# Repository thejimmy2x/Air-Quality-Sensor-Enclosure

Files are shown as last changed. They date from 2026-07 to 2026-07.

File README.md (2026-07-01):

# Sensor Stack Enclosure

Parametric, lidded desk enclosure for a multi-sensor air-quality stack, designed in
Fusion 360 (driven by User Parameters) for FDM printing (PETG/ASA, 0.6 mm nozzle).

## Sensor stack
| Board | Size (mm) | Role |
|---|---|---|
| ESP32-S3-DevKitC-1 | ~70 × 28 × 13 | MCU, heat source, external USB-C |
| PMS5003 | 50 × 38 × 21 | Particulate, fan, needs fresh ambient air |
| SCD40 (Adafruit) | ~26 × 18 × 8 | CO2, heat-sensitive |
| BME680 (Adafruit) | ~25 × 18 × 6 | VOC/T/RH/P, heat-sensitive |
| SGP40 (Adafruit) | ~25 × 18 × 5 | VOC index |

## Design
- **External:** ~155 × 83 × 39 mm. Low, wide slab; hex-honeycomb vents; filleted
  corners; chamfered floating base.
- **Thermal zoning:** hot back (PMS + ESP32) vs. cool front (gas sensors); SCD40
  placed farthest from heat.
- **Airflow:** passive honeycomb venting (front + both sides) for the gas sensors;
  PMS5003 isolated with a dedicated round fan-intake port + exhaust on the back wall.
- **Closure:** screw-down lid, M3 heat-set brass inserts (4 corners).
- **Features:** external USB-C port, status-LED light-pipe, removable carrier tray.

## Components (print each once)
- `export/base.3mf` / `.stl` — outer shell with vents, ports, insert bosses
- `export/tray.3mf` / `.stl` — removable sensor carrier (pockets, PMS/ESP cradles)
- `export/lid.3mf` / `.stl` — screw-down lid
- `export/sensor_enclosure_assembly.step` — full assembly (CAD interchange)

## Status
v1 complete. Fit-check TBDs (all parameterized): PMS intake/exhaust exact port
positions, LED light-pipe height, USB-C cutout size/height. See `STATE.md`.

## Build notes
- Fusion source is parametric (49 User Parameters). The Base is generated by a single
  consolidated script; clearances tuned for a 0.6 mm nozzle (pocket +0.5, tray 0.25,
  lid lip 0.4, M3 insert pilot 4.1 mm).

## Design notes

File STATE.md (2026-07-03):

# STATE — Sensor Stack Enclosure

**Project:** Sensor Enclosure (JDP3D) | **Owner:** Jimmy Pezzone
**Active track:** enclosure-v1
**Last updated:** 2026-07-01

## Current state
Working doc = **"Sensor_Case"** in Fusion (NOT saved — Jimmy saves manually).
Doc is now MULTI-COMPONENT: root has 3 occurrences — **Base** (body BaseShell),
**Tray** (TrayBody), **Lid** (LidBody), each its own component. (A separate
"Sensor_Case_snap" doc exists — DISREGARD it, not canonical.) v1 + fit-check
revisions applied:
- Tray + PMS5003 FIT CONFIRMED good (physical).
- Corner-post clearance scallops added; PMS intake raised; ESP/SGP share a wall.
- Gas-sensor bays reworked: side-wall wire channels + enlarged SCD-40 (see below).
- **PMS 4-hole air inlet ported (2026-07-01, see below).**
- **ESP USB port widened to dual-USB-C slot (2026-07-02, see below).**
Next: physical fit-test of the 3 gas sensors in the reworked bays; then RE-EXPORT
base (raised intake + new inlet slot are in NO exported file yet). GitHub main is
current through the gas-bay rework (commit c07a783), tray export = Sensor_Case_Tray_Final.stl.
Full plan: `C:\Users\jdp63\.claude\plans\i-have-a-sensor-quizzical-owl.md`

## Model summary (Fusion, 55 user params driving geometry)
- External size: **155.2 × 83.2 × ~39.4 mm** (base 32.4 tall + lid 7).
- Interior: 150 × 78 × 30 mm.
- **Base** (comp Base / body BaseShell): filleted shell, chamfered floating base,
  4 corner insert bosses (Ø8, 4.1mm pilot for M3 heat-set), back-wall ports
  (PMS fan Ø22 @ X25 + PMS 4-hole inlet slot @ X50/Z23.4 + ESP dual-USB-C slot
  @ X113-137/Z5.4-12.4), honeycomb
  vents front + both sides, LED light-pipe port. NOTE: PMS vent face has ONLY a fan
  + a 4-hole inlet row (no separate exhaust — old "rect exhaust" was a misconception).
- **Tray** (1 body): floor 2.5mm; 4 corner-post scallops (r=5.5, clears Ø8 posts);
  3 gas-sensor bays with wire channels on BOTH side (±X) walls — SCD40 26.5×23.8,
  BME680/SGP40 26.4×18.8; PMS cradle (open back → intake), ESP cradle (open back →
  USB), 2 front finger scallops. Full length 149.5 (0.25mm/side to cavity).
  NOTE base intake circle raised +2mm so tray floor no longer blocks it.
- **Lid** (1 body): 3mm plate, matching fillet + top chamfer, register lip (0.4mm
  clr, corner-notched), 4 M3 screw counterbores aligned to inserts.

## Board layout (mm, interior min-corner x0,y0)
scd(12,12) bme(50,12) sgp(85,12) | pms(12,38) esp(112,6). Corner bosses (4,4)(146,4)(4,74)(146,74).
Thermal zoning: hot back (PMS+ESP) vs cool front (gas sensors); SCD40 front-left, farthest from ESP.

## Exports (X:\JDP3D\sensor enclosure\export\)
sensor_enclosure_assembly.step + base/tray/lid .3mf + .stl (High refinement).

## Gas-sensor bay rework (2026-07-01, after tray/PMS fit confirmed good)
Tray + PMS5003 now fit perfectly. Reworked the 3 gas-sensor bays:
- WIRE CHANNELS were on the wrong wall (back +Y). Real Adafruit boards have
  STEMMA-QT connectors on LEFT+RIGHT (+/-X) edges. Solid side walls were also
  blocking the connectors from seating -> that was the "bays too small" symptom.
  Fix: channels moved to BOTH side walls (8mm wide, Y17-25), all 3 bays
  ("both ends wired out"). Old back notches removed.
- SCD-40 genuinely too small: board 25.5 x 22.8mm, bay was 19 deep. Enlarged
  bay to 26.5(X) x 23.8(Y), grown front+back; back wall clears PMS cradle 1.40mm.
- BME680/SGP40 bays set to 26.4 x 18.8 (fits 25.4 x 17.8 std footprint).
- SGP40 right channel breaches the shared SGP/ESP wall (routes to ESP).
- Implementation: DELETED old pocket joins+notch cuts (Extrude3-8, Sketch3-8),
  REBUILT 3 pockets (Pocket_SCD40/BME680/SGP40) + 6 channels (Chan_*_L/R) on
  the Z=4.9 floor-top plane (Plane2). Rebuild needed because sketches are
  unconstrained rects (can't edge-drag cleanly). Single valid body, all healthy.
- Board dims: SCD40 25.5x22.8 (Adafruit 5187, confirmed); BME680/SGP40 taken as
  25.4x17.8 std STEMMA-QT (Adafruit hides exact dims in image-only fab prints).
  VERIFY BME680/SGP40 footprints at physical fit; enlarge if needed.

## PMS5003 four-hole air inlet — ported (2026-07-01)
Problem: base back wall had NO opening for the PMS's 4 clean-air INLET holes (only
the fan Ø22 + a mislocated "exhaust" rect). Per datasheet the vent face has only a
fan + a 4-hole inlet row — no exhaust. The old rect (Base Sketch6/Extrude6, symmetric
cut on wall midplane Y=79.3) was at the right X/width but wrong height (Z9.9-18.9),
so the holes (world Z~23.4, up near the sensor top) sat against solid wall.
Fix: deleted old Extrude6 (heals wall), redrew Sketch6 rect, rebuilt symmetric cut
-> INLET SLOT world X42-58 (16mm) × Z20.9-25.9 (5mm), centered X50/Z23.4. Covers
all 4 holes (world X44-56) + ~2mm seat play. Fan Ø22 @ X25 left untouched.
Verified via pointContainment: slot = through-opening (matches fan/USB signature),
old-exhaust spot now solid. BaseShell single healthy body.
Sketch6 coord map (for future edits): sketch x = world X (cm); sketch y = -(world Z);
plane Y=7.93cm (wall midplane); symmetric cut 3.45mm/side clears 2.6mm wall.
TODO Jimmy: SAVE doc + RE-EXPORT base .3mf/.stl (slot not in any export yet).

## ESP32-S3 dual-USB-C port — widened (2026-07-02)
Board = ESP32-S3-DevKitC-1-N32R16V: has TWO USB-C connectors on its end (native
USB + UART), but base had only ONE centered cutout (X120-132) -> one cable couldn't
seat. Espressif docs give board outline but NOT connector X-positions (image-only).
Estimated connector centers ~world X119 & X130.5 (pair centered on 25.5mm board end,
board spans X112-137.5). Chose robust fix: ONE wide "letterbox" slot spanning the
full board end -> Base Sketch7/Extrude7 rebuilt to world X113-137 (24mm) × Z5.4-12.4,
symmetric cut through back wall. Guaranteed to clear both connectors regardless of
exact placement; wall solid outside X113-137. Verified via pointContainment.
If you ever want two neat cutouts instead: measure the two port centers + widths.
TODO Jimmy: SAVE + RE-EXPORT base (slot not in any export yet).

## Hardware spec — closure (read off Sensor_Case geometry 2026-07-01)
- Inserts: **M3 brass heat-set**, set into the 4 BASE corner POSTS (Ø8 boss),
  one per corner. Pocket = Ø4.1 x 6mm deep BLIND hole in each post TOP face
  (Z 26.4..32.4); install from top (lid side). NOT in the lid.
- Insert part: standard M3 (~4.0mm OD, ~5.7mm long, e.g. CNC Kitchen M3x5.7 or
  generic M3x5/M3x4). Do NOT use extra-long M3 (would bottom out in 6mm pocket).
- Screws: **M3 socket-head cap, ~M3x8** (M3x10 ok for max engagement). Head
  recesses in lid Ø6.2 x 3mm counterbore; lid clears post top via Ø9.8 recess;
  ~5mm thread engages the insert. No separate Ø3.4 lid clearance hole (Ø9.8 recess
  serves that). 4 screws total, one per corner.

## Locked decisions
- Fusion MCP parametric; screw-down lid + M3 heat-set inserts (no gasket).
- Passive honeycomb venting; PMS isolated w/ round fan-intake port + exhaust.
- Hex honeycomb aesthetic; USB-C port, LED light-pipe, removable carrier tray.
- Material/print: PETG or ASA, 0.6mm nozzle, walls 2.6 / floor 2.4.
- Clearances (0.6mm nozzle): pocket +0.5, tray 0.25, lid lip 0.4, insert pilot 4.1.

## Fit-check revisions (2026-07-01, doc "Sensor_Case" — NOT the NoInserts doc)
Physical fit-check drove 3 direct-geometry edits (sketches are script-built, no
parametric dims, so param changes don't move geometry — edited geometry directly):
1. Tray ESP/SGP compartment overlap: shifted SGP pocket (Sketch7 + wire-notch
   Sketch8) -0.6mm X. SGP right wall now X[109.90..111.50] == ESP cradle left wall
   -> single SHARED 1.6mm wall (was 2.2mm interpenetration).
2. Tray hit the 4 corner POSTS (base screw bosses Ø8 / r=4 at (4,4)(4,74)
   (146,4)(146,74), full-height). The 1.85mm left-edge trim did NOT fix this
   (posts are at the corners, not along the edge) -> REVERTED that trim.
   Real fix: feature "CornerPostClearance" = 4 circular corner cutouts r=5.5
   (Ø11) centered on each boss. Clears Ø8 posts by 1.55mm radial; tray restored
   to full length 149.5mm (snug in 150 cavity -> stays located over the intake).
   Note: r=5.5 chosen because corner tip is 5.30mm from boss center; a smaller
   r (tried 4.6) isolates the tip as a <1mm3 sliver, and deleting slivers via
   body.deleteMe() also deletes the parent cut feature -> use r>=tip distance.
3. PMS intake was blocked ~1.5mm by tray floor: raised base intake circle
   (Sketch5) +2.0mm. Center world Z 14.4 -> 16.4; bottom 3.4 -> 5.4, clears tray
   floor top (4.89) by +0.51mm. Exhaust unaffected (bottom already ~9.9).
NOTE: Tray is a REMOVABLE carrier (separate print), NOT print-in-place.
TODO for Jimmy: SAVE the doc manually + RE-EXPORT tray.3mf/.stl and base.3mf/.stl
(current repo exports are pre-revision). Intake clearance is thin (0.51mm) — raise
more if you want margin, but that walks away from the real PMS fan center (still TBD).

## Open items / fit-check TBDs
- [x] PMS5003 port coords RESOLVED via datasheet (Downloads\pms5003.jpg). Vent
      face (50×21, against back wall) = fan Ø12 @ 35.80mm from left edge + 4 inlet
      holes (row, 6mm from left, 12mm span/4mm pitch, 2.45mm below top edge).
      Sensor seated hole/fan-end toward +X (ESP side): fan→world X~26 (under Ø22),
      holes→world X44-56 near top (world Z~23.4). See PMS inlet section below.
- [ ] LED light-pipe height (front wall X126, Z25mm) — align to actual ESP LED.
- [ ] USB-C cutout height/size vs actual connector.
- [ ] Board heights/pocket depths at physical test fit.
- Honeycomb finalized: hex_af=5mm, rib=1.0mm, compact centered windows
  (front X35-115, left Y10-45, right Y33-68, Z band fl+5..fl+22). Base is now
  built by ONE consolidated script (shell+bosses+ports+LED+vents) -> easy to retune.

## Reusable notes / gotchas
- Fusion rejects param names 'wall' and 'floor' (reserved) -> used wall_t, floor_t.
- userParameter.value is in cm (internal units); positions built via mm()/10.
- Corner-notch circles can leave tiny disconnected slivers -> delete bodies <50mm3.
- Never save the Fusion document. Fusion MCP not thread-safe -> sequential calls only.
- MCP gotcha: Fusion MCP tools only load into a Claude Code session at startup;
  had to /reload-plugins (or restart session) after connecting the server.

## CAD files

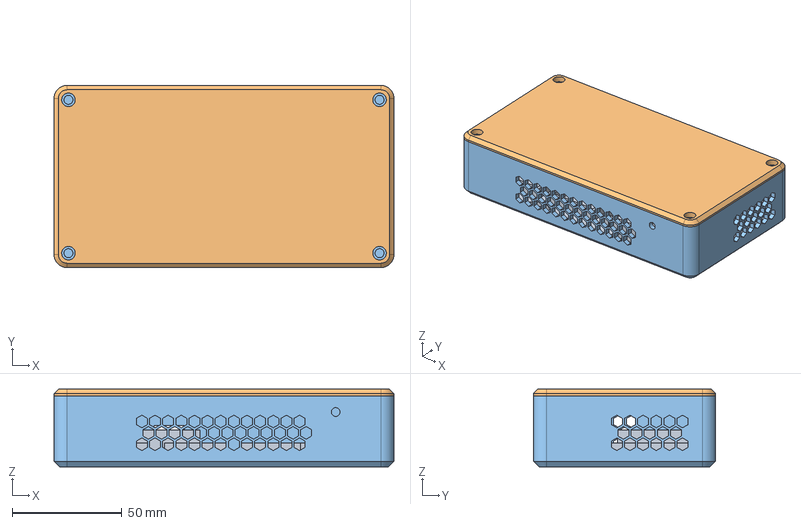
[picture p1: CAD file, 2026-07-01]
export/sensor_enclosure_assembly.step
155.2 x 83.2 x 35.4 mm
Base

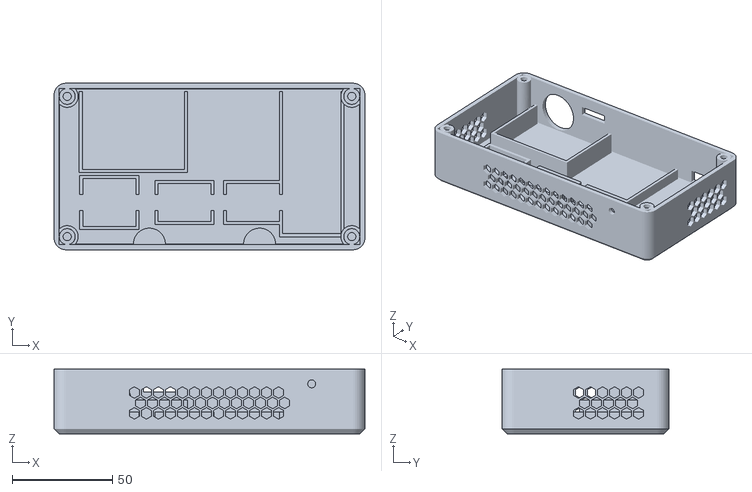
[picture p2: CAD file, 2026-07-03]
export/Sensor_Case.stl
155.2 x 83.2 x 32.4

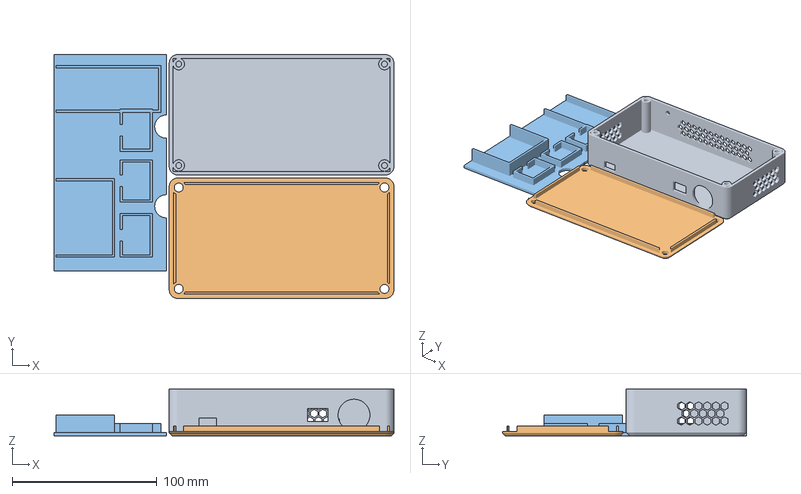
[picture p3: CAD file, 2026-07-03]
export/TestPrint1.3mf
234.7 x 168.4 x 32.4 mm
base.stl
lid.stl
tray.stl

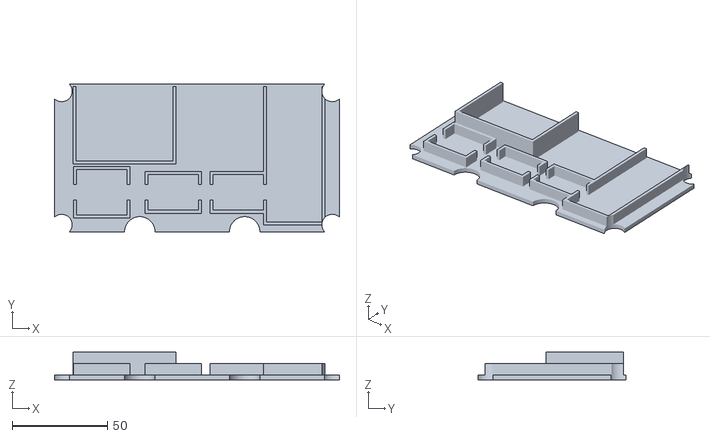
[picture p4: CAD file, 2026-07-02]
export/Sensor_Case_Tray_Final.stl
149.5 x 77.5 x 14.5

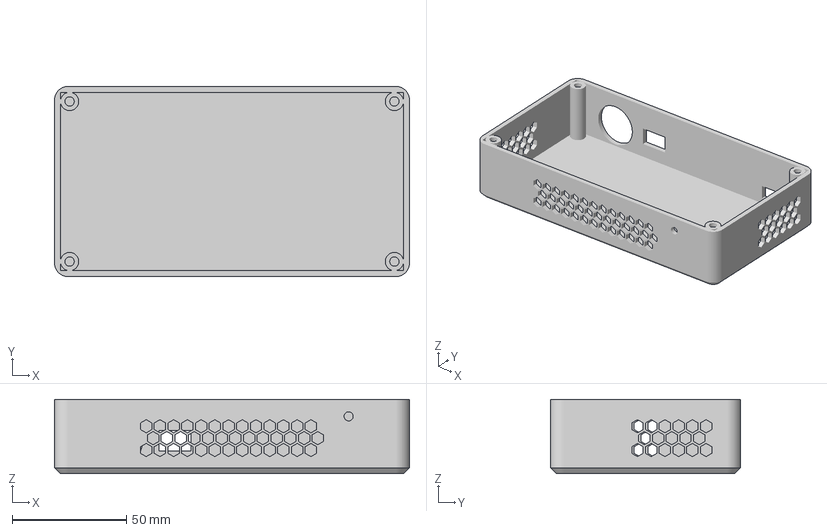
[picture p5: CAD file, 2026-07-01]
export/base.3mf
155.2 x 83.2 x 32.4 mm

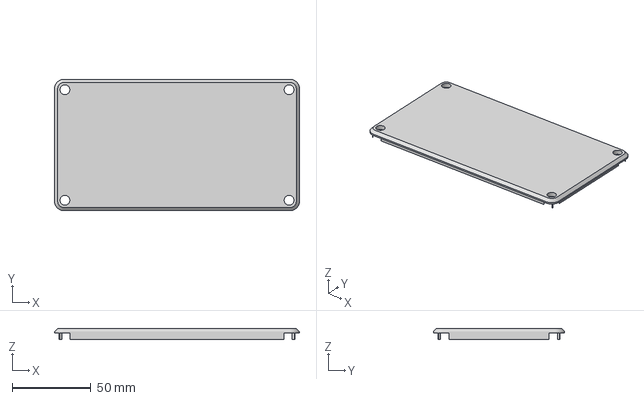
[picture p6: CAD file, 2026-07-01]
export/lid.3mf
155.2 x 83.2 x 7.00 mm

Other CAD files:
export/base.stl
export/lid.stl

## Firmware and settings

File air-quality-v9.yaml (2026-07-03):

esphome:
  name: air-quality-monitor
  friendly_name: Air Quality Monitor

esp32:
  board: esp32-s3-devkitc-1
  framework:
    type: esp-idf

wifi:
  ssid: !secret wifi_ssid
  password: !secret wifi_password
  ap:
    ssid: "Air-Quality-Monitor"
    password: !secret ap_password

captive_portal:

api:
  reboot_timeout: 0s

ota:
  - platform: esphome

web_server:
  port: 80

prometheus:

i2c:
  sda: GPIO8
  scl: GPIO9
  frequency: 100kHz

logger:
  hardware_uart: USB_SERIAL_JTAG
  level: DEBUG
  logs:
    pmsx003: WARN
    bme680.sensor: WARN
    scd4x: WARN
    sgp4x: WARN
    sensor: WARN

uart:
  id: uart_pms
  rx_pin: GPIO16
  tx_pin: GPIO17
  baud_rate: 9600

# Globals for tracking previous CO2 value and VOC baseline
globals:
  - id: previous_co2
    type: float
    restore_value: no
    initial_value: '0.0'
  - id: previous_co2_time
    type: unsigned long
    restore_value: no
    initial_value: '0'
  - id: voc_baseline
    type: float
    restore_value: yes
    initial_value: '100.0'

sensor:
  - platform: bme680
    temperature:
      name: "Temperature"
      id: bme_temperature
    pressure:
      name: "Pressure"
    humidity:
      name: "Humidity"
      id: bme_humidity
    gas_resistance:
      name: "Gas Resistance"
    address: 0x77
    update_interval: 30s
    heater:
      temperature: 320
      duration: 150ms

  - platform: pmsx003
    type: PMSX003
    uart_id: uart_pms
    pm_1_0:
      name: "PM1.0 Concentration"
      id: pm_1_0      
    pm_2_5:
      name: "PM2.5 Concentration"
      id: pm_2_5
    pm_10_0:
      name: "PM10.0 Concentration"
      id: pm_10_0

  - platform: scd4x
    co2:
      name: "CO2"
      id: co2_sensor
      on_value:
        then:
          - lambda: |-
              unsigned long now = millis();
              if (id(previous_co2_time) > 0) {
                float dt_min = (now - id(previous_co2_time)) / 60000.0;
                if (dt_min > 0) {
                  float rate = (x - id(previous_co2)) / dt_min;
                  id(co2_rate).publish_state(rate);
                }
              }
              id(previous_co2) = x;
              id(previous_co2_time) = now;
    temperature:
      name: "SCD41 Temperature"
    humidity:
      name: "SCD41 Humidity"
    update_interval: 60s

  - platform: sgp4x
    voc:
      name: "VOC Index"
      id: voc_index
      on_value:
        then:
          - lambda: |-
              // Update rolling baseline slowly (1% new reading, 99% old baseline)
              // This gives a ~100 sample trailing average
              id(voc_baseline) = (id(voc_baseline) * 0.99) + (x * 0.01);
              id(voc_deviation).publish_state(x - id(voc_baseline));
    compensation:
      humidity_source: bme_humidity
      temperature_source: bme_temperature

  # CO2 Rate of Change (ppm per minute)
  - platform: template
    name: "CO2 Rate of Change"
    id: co2_rate
    unit_of_measurement: "ppm/min"
    accuracy_decimals: 1
    icon: "mdi:trending-up"

  # VOC Deviation from baseline (positive = spike above normal)
  - platform: template
    name: "VOC Deviation"
    id: voc_deviation
    unit_of_measurement: ""
    accuracy_decimals: 1
    icon: "mdi:air-filter"

  # PM2.5 / PM10 Ratio (higher = more fine particles, combustion/off-gassing)
  - platform: template
    name: "PM2.5/PM10 Ratio"
    unit_of_measurement: ""
    accuracy_decimals: 2
    update_interval: 60s
    icon: "mdi:chart-donut"
    lambda: |-
      if (id(pm_10_0).state > 0) {
        return id(pm_2_5).state / id(pm_10_0).state;
      } else {
        return 0;
      }

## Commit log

2026-07-01 Initial commit: sensor stack enclosure v1
    Parametric Fusion 360 desk enclosure for ESP32-S3 + PMS5003 + SCD40 +
    BME680 + SGP40. Hex-honeycomb vents, thermal zoning, screw-down lid with
    M3 heat-set inserts, removable carrier tray. Includes STEP assembly and
    per-part 3MF/STL exports.
    [base.3mf, base.stl, lid.3mf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]
2026-07-01 Tray fit-check revisions: shared ESP/SGP wall, corner post clearances, raised PMS intake
    - ESP32/SGP compartments: shift SGP pocket -0.6mm so it shares one 1.6mm
    wall with the ESP cradle (was a 2.2mm interpenetration)
    - Corner fit: 4 circular corner cutouts (r=5.5) to clear the base Ø8
    screw posts; tray kept full length so it stays located over the intake
    - PMS5003 intake raised +2.0mm so it clears the tray floor (was ~1.5mm blocked)
    - Add revised tray export (Sensor_Case-TrayRev1.stl); log details in STATE.md
    [Sensor_Case-TrayRev1.stl]
2026-07-02 Rework gas-sensor bays: side-wall wire channels + enlarged SCD-40
    - Move wire channels from back wall to both left/right side walls on all
    three gas bays (STEMMA-QT connectors are on the L/R edges); removes the
    old back notches and the side-wall interference that blocked seating
    - Enlarge SCD-40 bay to 26.5 x 23.8mm for the 25.5 x 22.8mm board; back
    wall clears the PMS cradle by 1.40mm
    - Size BME680/SGP40 bays to the 25.4 x 17.8mm standard STEMMA-QT footprint
    - Rebuilt pockets + channels on the floor-top plane; single valid body
    - Add updated tray export; details logged in STATE.md
    [Sensor_Case_Tray_Final.stl]
2026-07-02 Refresh STATE.md top-level snapshot to current model state
    Current state and model summary now reflect the Sensor_Case working doc
    (55 params), applied fit-check revisions, gas-bay rework, and next steps.
2026-07-02 Remove superseded tray exports
    Delete v1 tray.stl/tray.3mf and Sensor_Case-TrayRev1.stl; the current tray
    lives in Sensor_Case_Tray_Final.stl.
    [Sensor_Case-TrayRev1.stl, tray.3mf, tray.stl]
2026-07-03 docs: log port fixes; add ESPHome config with secrets extracted
    - STATE.md: PMS 4-hole inlet slot (X50/Z23.4), ESP32-S3 dual-USB-C
    letterbox slot (X113-137), export dir -> X: drive
    - air-quality-v9.yaml: ESPHome config, WiFi creds moved to !secret
    - .gitignore: exclude secrets.yaml
    - add Sensor_Case.stl export, TestPrint1.3mf
    [Sensor_Case.stl, TestPrint1.3mf]
2026-11-10 docs+exports: STATE update, Sensor_Case print files (plain and painted)
